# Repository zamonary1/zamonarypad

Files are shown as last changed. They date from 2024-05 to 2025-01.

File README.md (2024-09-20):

# Zamonarypad

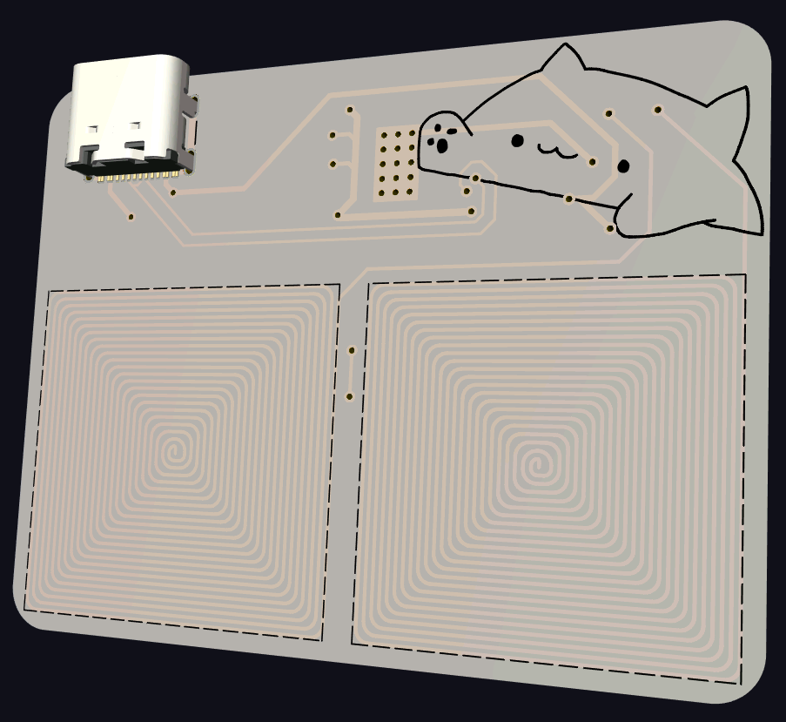
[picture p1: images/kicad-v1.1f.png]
Zamonarypad Keyboard


Zamonarypad is a low-latency capacitive touch 2-key keyboard. It is based on cheap ESP32-S2 microcontroller with native USB support.

Feel free to contact me via @zamonary1 via discord, i'll be happy to assist with any issues or questions you may have.

Code is licensed with BSD 3-Clause, PCB files are licensed with Creative Commons BY-SA 4.0. You can learn more in LICENSE

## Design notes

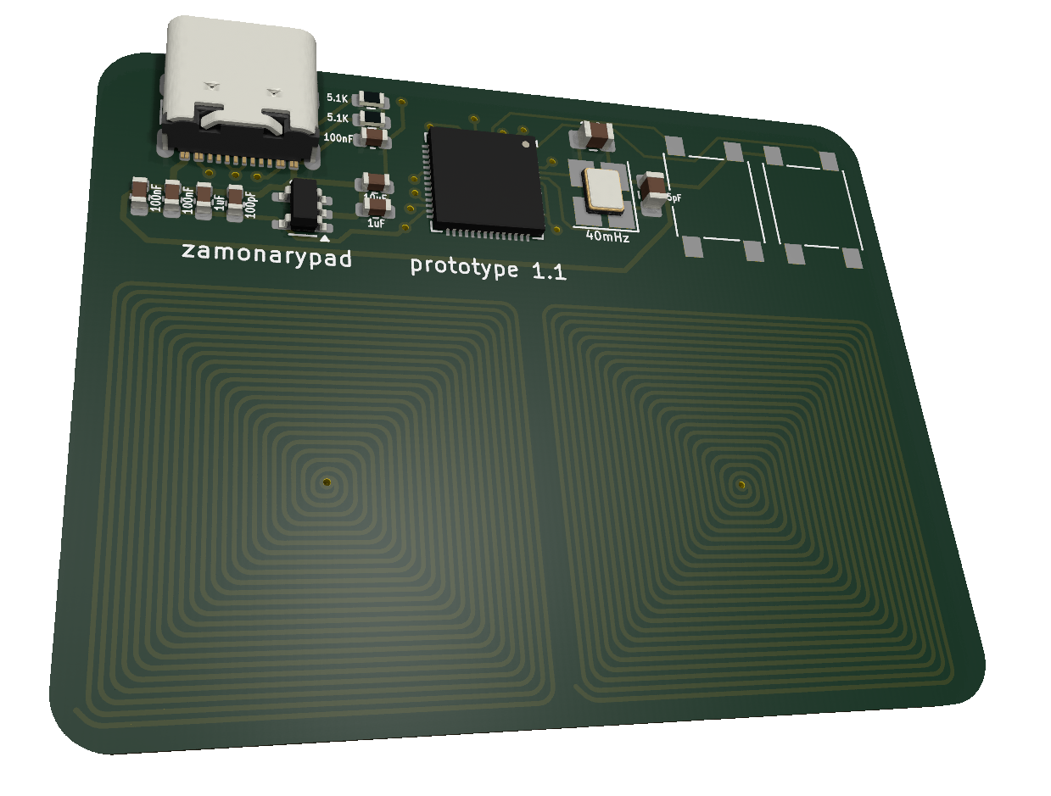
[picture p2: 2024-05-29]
images/kicad-1.png

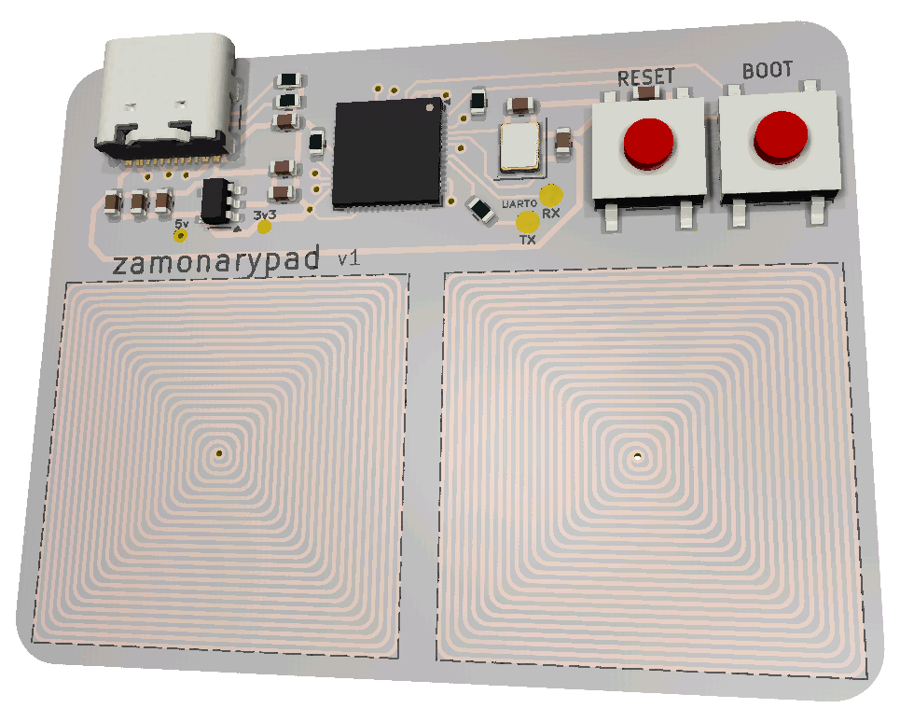
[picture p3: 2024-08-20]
images/kicad-2.png

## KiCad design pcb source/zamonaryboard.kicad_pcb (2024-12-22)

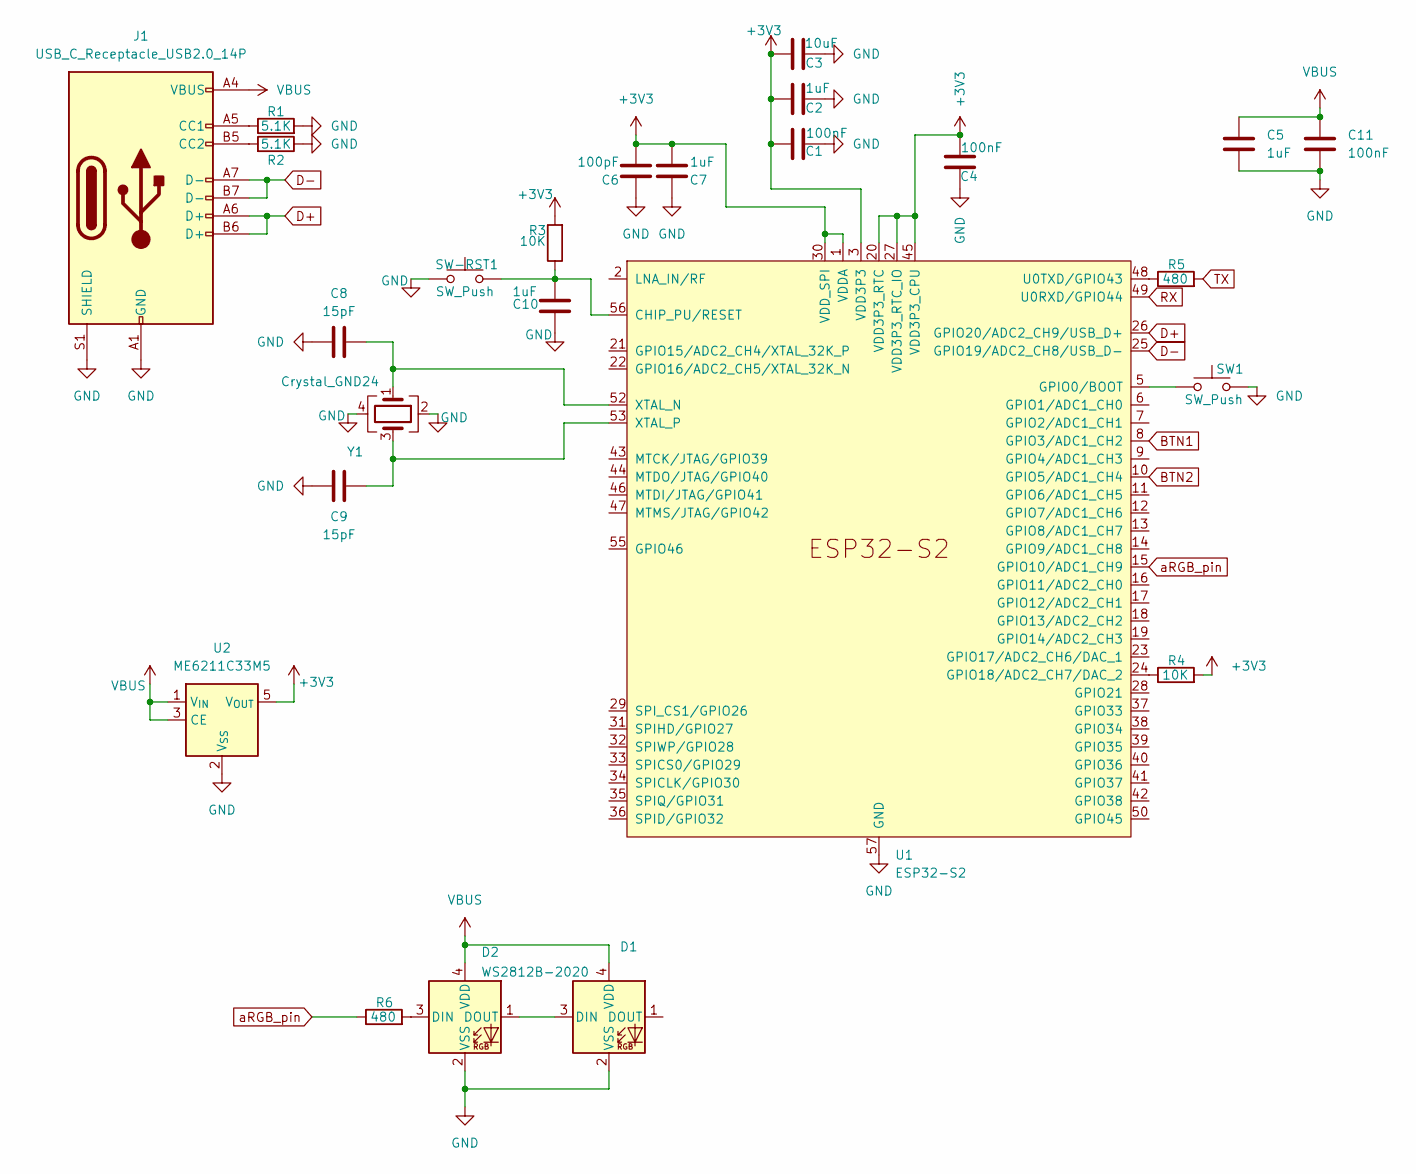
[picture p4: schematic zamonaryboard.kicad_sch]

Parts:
C1, C4: 100nF; C_0603_1608Metric; LCSC C14663
C2, C7: 1uF; C_0603_1608Metric; LCSC C15849
C3: 10uF; C_0603_1608Metric; LCSC C19702
C5: 1uF; C_0603_1608Metric
C6: 100pF; C_0603_1608Metric; LCSC C14665
C8, C9: 15pF; C_0603_1608Metric; LCSC C63339
C10: 1uF; C_0603_1608Metric; LCSC C14663
C11: 100nF; C_0603_1608Metric
D1, D2: WS2812B-2020; LED_WS2812B-2020_PLCC4_2.0x2.0mm
J1: USB_C_Receptacle_USB2.0_14P; USB_C_Receptacle_GCT_USB4105-xx-A_16P_TopMnt_Horizontal
R1, R2: 5.1K; R_0603_1608Metric; LCSC C23186
R3, R4: 10K; R_0603_1608Metric; LCSC C23186
R5, R6: 480; R_0603_1608Metric; LCSC C23186
SW1: SW_Push; SW_SPST_SKQG_WithoutStem
SW-RST1: SW_Push; SW_SPST_SKQG_WithoutStem
U1: ESP32-S2; QFN-56-1EP_7x7mm_P0.4mm_EP5.6x5.6mm
U2: ME6211C33M5; SOT-23-5
Y1: Crystal_GND24; Crystal_SMD_3225-4Pin_3.2x2.5mm; LCSC C9010

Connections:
+3V3: C1.1, C2.1, C3.1, C4.1, C6.1, C7.2, R3.2, R4.2, U1.1 (VDDA), U1.3 (VDD3P3), U1.4 (VDD3P3), U1.20 (VDD3P3_RTC), U1.27 (VDD3P3_RTC_IO), U1.30 (VDD_SPI), U1.45 (VDD3P3_CPU), U1.51 (VDDA), U1.54 (VDDA), U2.5 (V_{OUT})
BTN1: U1.8 (GPIO3/ADC1_CH2)
BTN2: U1.10 (GPIO5/ADC1_CH4)
D+: J1.A6 (D+), J1.B6 (D+), U1.26 (GPIO20/ADC2_CH9/USB_D+)
D-: J1.A7 (D-), J1.B7 (D-), U1.25 (GPIO19/ADC2_CH8/USB_D-)
GND: C1.2, C2.2, C3.2, C4.2, C5.2, C6.2, C7.1, C8.1, C9.1, C10.2, C11.2, D1.2 (VSS), D2.2 (VSS), J1.A1 (GND), J1.A12 (GND), J1.B1 (GND), J1.B12 (GND), J1.S1 (SHIELD), R1.2, R2.1, SW1.2, SW-RST1.1, U1.57 (GND), U2.2 (V_{SS}), Y1.2, Y1.4
unnamed: D1.3 (DIN), D2.1 (DOUT)
unnamed: D2.3 (DIN), R6.2
unnamed: J1.A5 (CC1), R1.1
unnamed: J1.B5 (CC2), R2.2
unnamed: C10.1, R3.1, SW-RST1.2, U1.56 (CHIP_PU/RESET)
unnamed: SW1.1, U1.5 (GPIO0/BOOT)
unnamed: R4.1, U1.24 (GPIO18/ADC2_CH7/DAC_2)
unnamed: R5.1, U1.48 (U0TXD/GPIO43)
unnamed: C8.2, U1.52 (XTAL_N), Y1.1
unnamed: C9.2, U1.53 (XTAL_P), Y1.3
RX: U1.49 (U0RXD/GPIO44)
TX: R5.2
VBUS: C5.1, C11.1, D1.4 (VDD), D2.4 (VDD), J1.A4 (VBUS), J1.A9 (VBUS), J1.B4 (VBUS), J1.B9 (VBUS), U2.1 (V_{IN}), U2.3 (CE)
aRGB_pin: R6.1, U1.15 (GPIO10/ADC1_CH9)

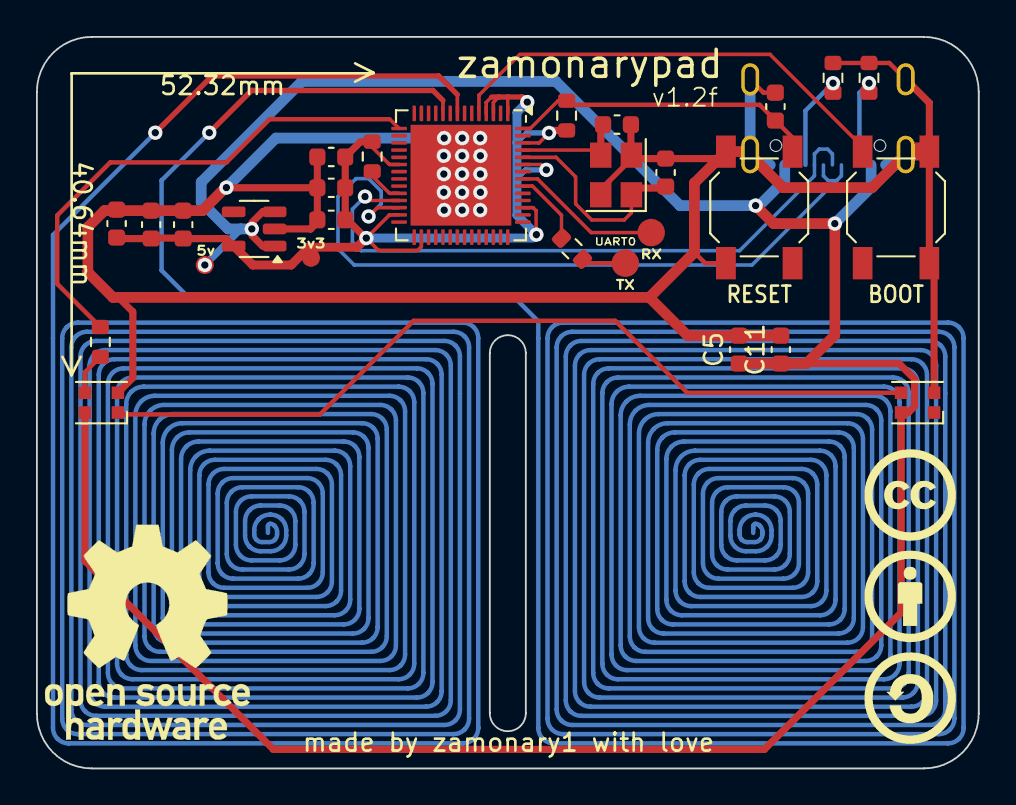
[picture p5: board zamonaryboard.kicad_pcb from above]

Board: 2 copper layers, 52.3 x 40.6 mm, 25 parts (1 on the bottom side), 16 nets.

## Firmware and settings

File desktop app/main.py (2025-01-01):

import dearpygui.dearpygui as dpg
import pymsgbox
import serial
import serial.tools.list_ports
import time
import json
import scipy.interpolate
xxxzzxxzzxxxzzzzzxzxxzxzxzxzxzxzzxzxzxzxzxzxzxzzxzzxzxxzxxzzxxzxzxzxzzxzzxzx
# global variables
ser = None
lasttime = time.time()
json_response = {"button1val":0,"button2val":0,"button1sens":0,"button2sens":0,"button1val_raw":0,"button2val_raw":0}
json_response_raw = json_response
min1 = float('inf')
min2 = float('inf')
max1 = float('-inf')
max2 = float('-inf')
delay_between_reads = 0.033 #33ms between updates or 30 updates per second
# get availible serial interfaces
def get_serial_ports():
    ports = serial.tools.list_ports.comports()
    ports = [port.device for port in ports]
    ports = [x for x in ports if 'ttyACM' in x] #keep only elements containing ttyACM
    if ports == []: 
        try: 
            dpg.set_value("connection_status", "Device not found")
            dpg.hide_item(serial_devices_list)
        except SystemError: next
    else:
        try: 
            dpg.set_value("connection_status", f"Found {len(ports)} devices")
            dpg.show_item(serial_devices_list)
        except SystemError: next
    return ports

# create serial connection
def connect_serial():
    global ser
    port = dpg.get_value("serial_port")
    try:
        ser = serial.Serial(port, 115200, timeout=1)
        dpg.set_value("connection_status", f"Connected to {port}")
        lasttime = time.time()
    except serial.SerialException as err:
        print(err)
        ser = None
        if 'Device or resource busy' in str(err):
            dpg.set_value("connection_status", "Failed to connect:\nDevice or resource busy")
        else: dpg.set_value("connection_status", "Failed to connect")

def refresh_serial():
    dpg.configure_item("serial_port", items=get_serial_ports())
    
def lostConnection():
    ser = None
    refresh_serial()
    dpg.set_value("connection_status", "Lost connection")
    dpg.set_value("progress_bar_1", 0.0)
    dpg.set_value("progress_bar_2", 0.0)
    json_response = json.loads('{"button1val":0,"button2val":0}') #reset button statusbars to 0

def readbuttonvalues(raw = False):
    global lasttime
    global json_response
    global min1
    global min2
    global max1
    global max2
    global ser
    
    if lasttime + delay_between_reads < time.time() and ser != None:
        try: ser.write(b'read\n')
        except Exception:
            if ser != None:
                lostConnection()
                return 0
        # ser.write(b'read\n')

        try: json_response = json.loads(ser.readline())
        except serial.serialutil.SerialException:
            lostConnection()
            return 0
        #print(json_response)
        
        min1 = min(min1, int(json_response['button1val']))
        min2 = min(min2, int(json_response['button2val']))
        max1 = max(max1, int(json_response['button1val']))
        max2 = max(max2, int(json_response['button2val']))
        
        json_response['button1val_raw'] = json_response['button1val']
        json_response['button2val_raw'] = json_response['button2val']
        
        if max1 - min1 != 0:
            json_response['button1val'] = (int(json_response['button1val']) - min1) / (max1 - min1) * 100
        else:
            json_response['button1val'] = 0

        if max2 - min2 != 0:
            json_response['button2val'] = (int(json_response['button2val']) - min2) / (max2 - min2) * 100
        else:
            json_response['button2val'] = 0
        
        lasttime += delay_between_reads
    
    if raw: 
        ser.write(b'read\n')
        return(json.loads(ser.readline()))
    
    return(json_response)

def send_sens_values(btn1_sens, btn2_sens):
    if ser is not None:
        json_response = readbuttonvalues()
        val_btn1_idle = int(json_response["button1val_raw"])
        val_btn2_idle = int(json_response["button2val_raw"])
        print(f"sens1 = {val_btn1_idle + btn1_sens}, sens2 = {val_btn2_idle + btn2_sens}")
        time.sleep(0.1)
        ser.write(f'wrbtn1 {val_btn1_idle + btn1_sens}\n'.encode())
        time.sleep(0.1)
        ser.write(f'wrbtn2 {val_btn2_idle + btn2_sens}\n'.encode())
        print(ser.readline())
        return(True)
    else: return(False)

def calibrate_btn():
    #Data was measured by me
    x_grams =    [0.25, 0.45,  1.25,  1.6,   3.9,   9.5,   14,    29.6 ]
    y_measured = [6000, 10000, 15000, 20000, 35000, 50000, 60000, 70000]

    if ser is not None:
        
        #pymsgbox.alert(text="Do not touch the zamonaryboard and press OK", title='', button='OK')
        sensitivity = int(pymsgbox.prompt(text="Enter the sensitivity (grams) and do NOT touch the buttons", title='' , default='1'))

        cs = scipy.interpolate.CubicSpline(x_grams, y_measured, bc_type='natural')
        
        sensitivity = int(cs(sensitivity+0.3))

        send_sens_values(sensitivity, sensitivity)
        pymsgbox.alert(text="Success", title='', button='OK')



    
    

    
dpg.create_context()
dpg.create_viewport(title='Zamonarypad', width=200, height=400)
dpg.setup_dearpygui()

with dpg.window(tag="mainwin"):

    # droplist of all serial devices
    print("created window instance")
    serial_ports = get_serial_ports()
    print(serial_ports)
    serial_devices_list = dpg.add_combo(serial_ports, default_value=serial_ports[0] if serial_ports else "", tag="serial_port")

    dpg.add_button(callback=connect_serial, label='connect')
    dpg.add_button(callback=refresh_serial, label='refresh')

    button_bar_1 = dpg.add_progress_bar(label="1", default_value=0, tag="progress_bar_1")
    button_bar_2 = dpg.add_progress_bar(label="2", default_value=0, tag="progress_bar_2")
    
    dpg.add_button(callback=calibrate_btn, label='calibrate')

    dpg.add_text("", tag="connection_status")
    dpg.add_text("", tag="values")

dpg.show_viewport()
dpg.set_primary_window("mainwin", True)




while dpg.is_dearpygui_running():
    
    readbuttonvalues()
    
    
    
    dpg.set_value("progress_bar_1", json_response['button1val']/100.0)
    dpg.set_value("progress_bar_2", json_response['button2val']/100.0)
    dpg.set_value("values", (json_response['button1val_raw'], json_response['button2val_raw']))
    dpg.render_dearpygui_frame()
dpg.destroy_context()

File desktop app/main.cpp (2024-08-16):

#include <gtkmm.h>
#include <iostream>

/*
static const std::string ui_data = R"(

)";
*/

/*
class MainWindow : public Gtk::Window {
public:
  MainWindow() :
    //builder(Gtk::Builder::create_from_string(ui_data)) {
    builder(Gtk::Builder::create_from_file("padapp.ui")) {

  }
protected:
  Glib::RefPtr<Gtk::Builder> builder;
};
*/


namespace
{
Gtk::Window* pDialog = nullptr;
Glib::RefPtr<Gtk::Application> app;

void on_button_clicked()
{
  if (pDialog)
    pDialog->set_visible(false); // set_visible(false) will cause Gtk::Application::run() to end.
}

void on_app_activate()
{
  // Load the GtkBuilder file and instantiate its widgets:
  auto refBuilder = Gtk::Builder::create();
  try
  {
    refBuilder->add_from_file("padapp.ui");
  }
  catch(const Glib::FileError& ex)
  {
    std::cerr << "FileError: " << ex.what() << std::endl;
    return;
  }
  catch(const Glib::MarkupError& ex)
  {
    std::cerr << "MarkupError: " << ex.what() << std::endl;
    return;
  }
  catch(const Gtk::BuilderError& ex)
  {
    std::cerr << "BuilderError: " << ex.what() << std::endl;
    return;
  }

  // Get the GtkBuilder-instantiated dialog:
  pDialog = refBuilder->get_widget<Gtk::Window>("GtkWindow");
  if (!pDialog)
  {
    std::cerr << "Could not get the dialog" << std::endl;
    return;
  }

  // Get the GtkBuilder-instantiated button, and connect a signal handler:
  auto pButton = refBuilder->get_widget<Gtk::Button>("quit_button");
  if (pButton)
    pButton->signal_clicked().connect([] () { on_button_clicked(); });

  // It's not possible to delete widgets after app->run() has returned.
  // Delete the dialog with its child widgets before app->run() returns.
  pDialog->signal_hide().connect([] () { delete pDialog; });

  app->add_window(*pDialog);
  pDialog->set_visible(true);
}
} // anonymous namespace

int main(int argc, char** argv)
{
  auto app = Gtk::Application::create("io.github.zamonary1.padapp");

  // Instantiate a dialog when the application has been activated.
  // This can only be done after the application has been registered.
  // It's possible to call app->register_application() explicitly, but
  // usually it's easier to let app->run() do it for you.
  app->signal_activate().connect([] () { on_app_activate(); });

  return app->run(argc, argv);
}

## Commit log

2024-05-29 v0.1.1 fix
    [zamonaryboard-B_Cu.gbr, zamonaryboard-B_Mask.gbr, zamonaryboard-B_Paste.gbr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]
2024-05-29 initial images
    [zamonaryboard.kicad_pcb]
2024-06-15 Added jlcpcb component annotations, small improvements
    [zamonaryboard-B_Cu.gbr, zamonaryboard-B_Mask.gbr, zamonaryboard-B_Paste.gbr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]
2024-07-01 big improvements to pcb
    [zamonaryboard.kicad_pcb, zamonaryboard.kicad_sch]
2024-07-01 exported gerber files for prototype 1.3, cleanup
    [zamonaryboard.kicad_pcb, zamonaryboard.kicad_sch]
2024-07-02 Many improvements to pcb and scheme, added testpoints for easier debugging
    [zamonaryboard.kicad_pcb, zamonaryboard.kicad_sch]
2024-07-04 improved routing, fixes
    [zamonaryboard.kicad_pcb]
2024-07-04 Improvements on pcb, more components, better routing and better labling.
    [zamonaryboard.kicad_pcb, zamonaryboard.kicad_sch]
2024-07-27 small improvements, cleanup
    [zamonaryboard.kicad_pcb, zamonaryboard.kicad_sch]
2024-07-28 lower latency because of switch from interrupts to directly reading the touch values
2024-08-16 firmware improvements
    [zamonaryboard.kicad_pcb, zamonaryboard.kicad_sch]
2024-08-17 Python desktop app improvements, PCB pre-v1
    [zamonaryboard.kicad_pcb]
2024-08-20 v1 commit, desktop app improvements
    [zamonaryboard.kicad_pcb, zamonaryboard.kicad_sch]
2024-08-26 BIG improvements to firmware, 200 times more efficient now, had to artificially lower the poll rate to 1000hz for buttons to function properly
    [zamonaryboard.kicad_pcb]
2024-09-10 Flipped type-c port and main buttons to the back side, changed reset/boot button to be slimmer, initial new branch commit
    [zamonaryboard.kicad_pcb, zamonaryboard.kicad_sch]
2024-09-20 WS2812 2020 on the pcb! Not necesseary for proper work
    [zamonaryboard.kicad_pcb, zamonaryboard.kicad_sch]
2024-10-01 v1.2-f, added WS2812-2020 argb leds on the backside of the board (unnecesseary), improvements to pcb routing
    [zamonaryboard.kicad_pcb, zamonaryboard.kicad_sch]
2024-10-17 Added a cut between sensitive pads to give some tactile feedback to the board.
    [zamonaryboard.kicad_pcb]
2024-12-22 Firmware code cleanup, add support for addressible LEDs.
    [zamonaryboard.kicad_pcb, zamonaryboard.kicad_sch]
